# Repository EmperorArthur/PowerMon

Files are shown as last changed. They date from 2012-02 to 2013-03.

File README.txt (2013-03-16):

This is the code and Eagle files for a wireless power monitoring system.
All code and schematics are Copyright Arthur Moore 2013 GPLV3
	If this license is too restrictive for your use, feel free to contact me.

The wireless power monitor works using two boards with IEE 802.15.4 Radios.
One board monitors and transmits power usage data, while the other recieves the data, and sends it on to a computer.

Currently there is one board that does everything.  It uses an ATMega328 microcontroller with an AT86RF231 radio module.

This repository was taken from an SVN snapshot, then sanitized for public release.

The code is in ./Code/Datalogger1/

Important files are:
ADC.h/c:				These are the Analog to Digital Converter functions.
LED.h/c:				Simple functions to controll a LED
Communication.h/c:		Bridge functions, allowing cout to work with both serial and the radio.
UART.h/c:				Serial I/O for cout and cin
Measurements.h/c:		Where the actual measurements are done and calculated.
Datalogger1.c:			The main file.  This is where the important stuff takes place.

Contrary to any common sense, the main board is in ./Eagle Files/Main Board with Headers/

The only header on the board is a SPI programming header.
I normally use an arduino bootloader with the FTDI chip, so it's mostly unused.
There is one wire missing for this configuration.  A wire from the FTDI chip to the reset pin with a small capacitor in series.

I was orriginally using an older version of the radio library provided here:  http://simonetti.media.mit.edu/dev/projects/avrradio
Given my issues with the library documentation and microcontroller space issues, I had to hack the provided library to pieces.
I eventually ended up creating my own library from scratch for this thing.  See my github page for it.

To Do:
	Replace hacked together radio library with the one I created.
	Re-organize the repository so It's easy to understand, and doesn't have as many misc files.
	Completely redesign board for smaller footprint, less component count, and higher acuracy.
	Potentially seperate board into two seperate boards.

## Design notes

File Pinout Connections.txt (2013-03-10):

LED_Out 	PD5
IRQ			PB1
SLP_TR		PB0
/Radio_RST	PD6
CS-SD_Card	PD3

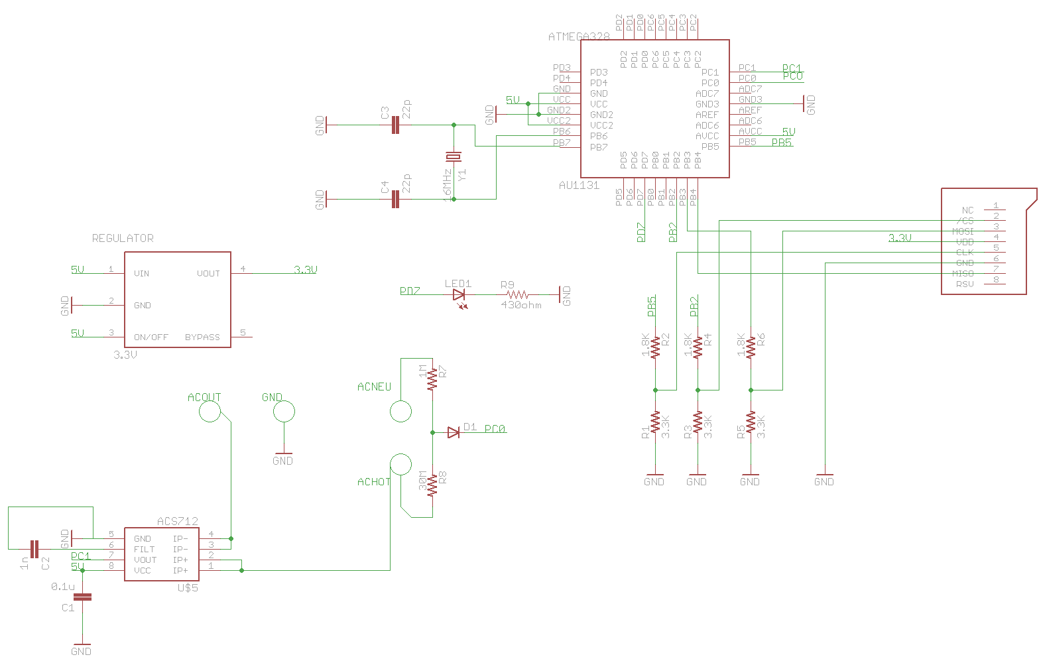
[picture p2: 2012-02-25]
Eagle Files/495Group10/final.png

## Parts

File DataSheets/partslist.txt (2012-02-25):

Crystal 16mHZ---Crystal, HC49US

SENSOR CURRENT 20A 5V BI 8-SOIC---- ACS712, SOIC-8

CONN MINI MICRO-SD 8PIN PCB GOLD---Micro SD socket PP

RES 909K OHM 1/4W 1% 1206 SMD---AXIAL-0.4, R1206, R1206W

RES 30M OHM 1/8W 5% 0805 SMD---R0805W, or R0805

ATMEGA328-AU---ATMEGA328,TQFP32A

IC LDO REG 3.3V 150MA SOT23-5---REG3.3V, SOT23-5

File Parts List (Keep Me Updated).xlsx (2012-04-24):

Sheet: Sheet1
Qty | Value | Device | Parts | Price Per Part | Price Per Board | For 3 Boards | Part Order Page | Part Description | Minimum Order
1 | ACS712 | ACS712 | CURRENT_SENSOR | $4.52 | $4.52 | $13.56 | http://parts.digikey.com/1/parts/945626-sensor-current-20a-5v-bi-8-soic-acs712elctr-20a-t.html | current-sensor | 3
1 | ANTENNA2SMD | ANTENNA2SMD | ANTENNA | $0.84 | $0.84 | $8.44 | http://search.digikey.com/us/en/products/2450AT18B100E/712-1006-1-ND/1560835 | RF antenna | Order at least 10
1 | AT86RF231(RADIO)AT86RF231 | AT86RF231(RADIO)AT86RF231 | AT86RF231 | $4.73 | $4.73 | $14.19 | http://search.digikey.com/us/en/products/AT86RF231-ZU/AT86RF231-ZU-ND/1870495 | radio | 3
1 | ATMEGA32832A | ATMEGA32832A | ATMEGA328 | $3.83 | $3.83 | $11.49 | http://parts.digikey.com/1/parts/1877362-ic-mcu-avr-32k-flash-32tqfp-atmega328-au.html | atmega | 3
1 | AVR_SPI_PRG_6PTH | AVR_SPI_PRG_6PTH | ISP_HEADER | $0.39 | $0.39 | $3.15 | http://search.digikey.com/us/en/products/961206-6404-AR/3M9459-ND/2071500 | ISP header | Order at least 10
2 | 0.1u | CAP0603-CAP | C1, C9 | $0.01 | $0.02 | $0.76 | http://search.digikey.com/us/en/products/CC0603ZRY5V9BB104/311-1343-1-ND/2103127 | 0.1uF Cap | Order at least 100
4 | 1 uF | CAP0603-CAP | CB1, CB2, CB3, CB4 | $0.02 | $0.07 | $1.87 | http://search.digikey.com/us/en/products/C1608Y5V1A105Z/445-1328-1-ND/567635 | 1 uF Caps | Order at least 100
1 | 1n | CAP0603-CAP | C2 | $0.02 | $0.02 | $1.53 | http://search.digikey.com/us/en/products/GRM188R71H102KA01D/490-1494-1-ND/587851 | 1nF Cap | Order at least 100
1 | 10 nF | CAP0603-CAP | C12 | $0.01 | $0.01 | $1.40 | http://search.digikey.com/us/en/products/GRM188R71H103KA01D/490-1512-1-ND/587862 | 10nF Cap | Order at least 100
2 | 12 pF | CAP0603-CAP | CX1, CX2 | $0.01 | $0.03 | $1.38 | http://search.digikey.com/us/en/products/C1608C0G1H120J/445-1270-1-ND/567672 | 12pF Caps | Order at least 100
4 | 22 pF | CAP0603-CAP | C3, C4, C10, C11 | $0.01 | $0.06 | $1.38 | http://search.digikey.com/us/en/products/C1608C0G1H220J/445-1273-1-ND/567670 | 22pF Caps | Order at least 100
3 |  | CAPPTH1 | C6, C7, C8 | - | - | - | - | Ignore these
1 | 3300µF | CAPPTH1 | C5 | $0.90 | $0.90 | $2.70 | http://search.digikey.com/us/en/products/ECA-1CM332/P5144-ND/245003 | 3300uF Cap | 3
2 | 16 MHZ | CRYSTALSMD | Y1, Y2 | $0.36 | $0.72 | $3.58 | http://parts.digikey.com/1/parts/1800664-crystal-16-000-mhz-18pf-smd-abls-16-000mhz-b4-t.html | 16mhz crystal | Order at least 10
1 | 115V -> 5V | EI38-2 | MT2201 | $4.96 | $4.96 | $14.88 | http://search.digikey.com/us/en/products/3FS-210/MT2201-ND/285599 | transformer | 3
1 | FT232RL | FT232RL | IC1 | $4.50 | $4.50 | $13.50 | http://search.digikey.com/scripts/DkSearch/dksus.dll?Detail&itemSeq=112820000&uq=634689795876532809 | USB-Serial Chip | 3
2 | Green | LED0603 | PWR, RF-RX | $0.09 | $0.19 | $2.34 | http://search.digikey.com/us/en/products/APT1608SGC/754-1121-1-ND/1747838 | green led | Order at least 25
2 | Red | LED0603 | RF-TX, STATUS | $0.09 | $0.19 | $2.34 | http://search.digikey.com/us/en/products/APT1608EC/754-1117-1-ND/1747834 | red led | Order at least 25
2 | MB4S | MB4S | B1, B2 | $0.41 | $0.83 | $4.14 | http://search.digikey.com/scripts/DkSearch/dksus.dll?Detail&itemSeq=112820148&uq=634689795876532809 | bridge rectifier | Order at least 10
1 | MICROSD | MICROSD | MICROSD | $1.94 | $1.94 | $5.82 | http://parts.digikey.com/1/parts/1804297-conn-mini-micro-sd-8pin-pcb-gold-101-00581-59.html | microsd | 3
1 | MINI-USB-UX60A-MB-5ST | MINI-USB-UX60A-MB-5ST | X2 | $1.02 | $1.02 | $10.23 | http://search.digikey.com/us/en/products/UX60A-MB-5ST/H2961CT-ND/597540 | mini USB | Order at least 10
3 |  | PTH3MM | ACHOT, ACNEU, ACOUT | - | - | - | - | Ignore these
1 | REG3.3V | REG3.3V | 3.3V_REGULATOR | $0.54 | $0.54 | $5.42 | http://parts.digikey.com/1/parts/609150-ic-ldo-reg-3-3v-150ma-sot23-5-lp2985-33dbvr.html | 3.3v regulator | Order at least 10
5 | 10K | RESISTOR0603-RES | R1, R2, R3, R4, R13 | $0.02 | $0.08 | $1.58 | http://search.digikey.com/us/en/products/RNCP0603FTD10K0/RNCP0603FTD10K0CT-ND/2240478 | 10k resistor | Order at least 100
1 | 37.4K | RESISTOR0603-RES | R12 | $0.02 | $0.02 | $1.58 | http://search.digikey.com/us/en/products/RNCP0603FTD37K4/RNCP0603FTD37K4CT-ND/2240497 | 37.4K resistor | Order at least 100
3 | 100 | RESISTOR0603-RES | R5, R6, R9 | $0.02 | $0.05 | $1.58 | http://search.digikey.com/us/en/products/RNCP0603FTD100R/RNCP0603FTD100RCT-ND/2240425 | 100 ohm resistor | Order at least 100
4 | STAND-OFF | STAND-OFF | JP1, JP2, JP3, JP4 | - | - | - | - | Ignore these
1 | WE-BAL | WE-BAL | BALUN | $2.58 | $2.58 | $7.74 | http://parts.digikey.com/1/parts/1790682-balun-ember351-357-0805-smd-748421245.html | balun | 3
1 |  |  | To Outlet | $0.80 | $0.80 | $7.97 | http://search.digikey.com/us/en/products/703W-00%2F07/Q335-ND/1164206 | Euro IN | Order at least 10
1 |  |  | To Device | $1.13 | $1.13 | $3.39 | http://search.digikey.com/us/en/products/4300.0701/486-1082-ND/1207600 | Edison Out | 3
1 |  |  | Fuse Holder | $1.83 | $1.83 | $9.16 | http://search.digikey.com/us/en/products/03540901ZXGY/F3131-ND/554005 | fuse holder | Order at least 5
1 |  |  | Fuse | $0.33 | $0.33 | $3.28 | http://search.digikey.com/us/en/products/3SB%2015-R/507-1537-ND/1009761 | 15A Fuse | Order at least 10
1 |  |  | Case | $5.83 | $5.83 | $17.49 | http://search.digikey.com/us/en/products/133,BK/SR133B-ND/95399 | Enclosure | 3
 |  |  | Wire
 |  |  | Board Cost | See Provided Rubric |  |  | http://www.pcb-pool.com/ppus/order_productconfiguration_js.html
1 |  |  | Alternate Resistor | $0.02 | $0.02 | $1.58 | http://search.digikey.com/us/en/products/RNCP0603FTD7K50/RNCP0603FTD7K50CT-ND/2240474 | 7.5K Alternate | Order at least 100
1 |  |  | Alternate Resistor | $0.02 | $0.02 | $1.58 | http://search.digikey.com/us/en/products/RNCP0603FTD14K0/RNCP0603FTD14K0CT-ND/2240484 | 14K Alternate | Order at least 100
 |  |  |  |  | $42.97 | $181.03 | Total
 |  |  |  |  |  | -$52.12 | Cost overhead from spare/unused parts

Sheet: Sheet2
Qty | Value | Device | Parts
1 | ACS712 | ACS712 | CURRENT_SENSOR
1 | ANTENNA2SMD | ANTENNA2SMD | ANTENNA
1 | AT86RF231(RADIO)AT86RF231 | AT86RF231(RADIO)AT86RF231 | AT86RF231
1 | ATMEGA32832A | ATMEGA32832A | ATMEGA328
1 | AVR_SPI_PRG_6PTH | AVR_SPI_PRG_6PTH | ISP_HEADER
2 | 0.1u | CAP0603-CAP | C1, C9
4 | 1 uF | CAP0603-CAP | CB1, CB2, CB3, CB4
1 | 1n | CAP0603-CAP | C2
1 | 10 nF | CAP0603-CAP | C12
2 | 12 pF | CAP0603-CAP | CX1, CX2
4 | 22 pF | CAP0603-CAP | C3, C4, C10, C11
3 |  | CAPPTH1 | C6, C7, C8
1 | 3300µF | CAPPTH1 | C5
2 | 16 MHZ | CRYSTALSMD | Y1, Y2
1 | 115V -> 5V | EI38-2 | MT2201
1 | FT232RL | FT232RL | IC1
2 | Green | LED0603 | PWR, RF-RX
2 | Red | LED0603 | RF-TX, STATUS
2 | MB4S | MB4S | B1, B2
1 | MICROSD | MICROSD | MICROSD
1 | MINI-USB-UX60A-MB-5ST | MINI-USB-UX60A-MB-5ST | X2
3 |  | PTH3MM | ACHOT, ACNEU, ACOUT
1 | REG3.3V | REG3.3V | 3.3V_REGULATOR
5 | 10K | RESISTOR0603-RES | R1, R2, R3, R4, R13
1 | 37.4K | RESISTOR0603-RES | R12
3 | 100 | RESISTOR0603-RES | R5, R6, R9
4 | STAND-OFF | STAND-OFF | JP1, JP2, JP3, JP4
1 | WE-BAL | WE-BAL | BALUN

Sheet: Sheet3
$0.05 | $0.24 | $1.90 | http://search.digikey.com/us/en/products/4-103741-0/A26509-40-ND/297917 | Pins for Jumper | no | This is for 40, our jumper uses 3

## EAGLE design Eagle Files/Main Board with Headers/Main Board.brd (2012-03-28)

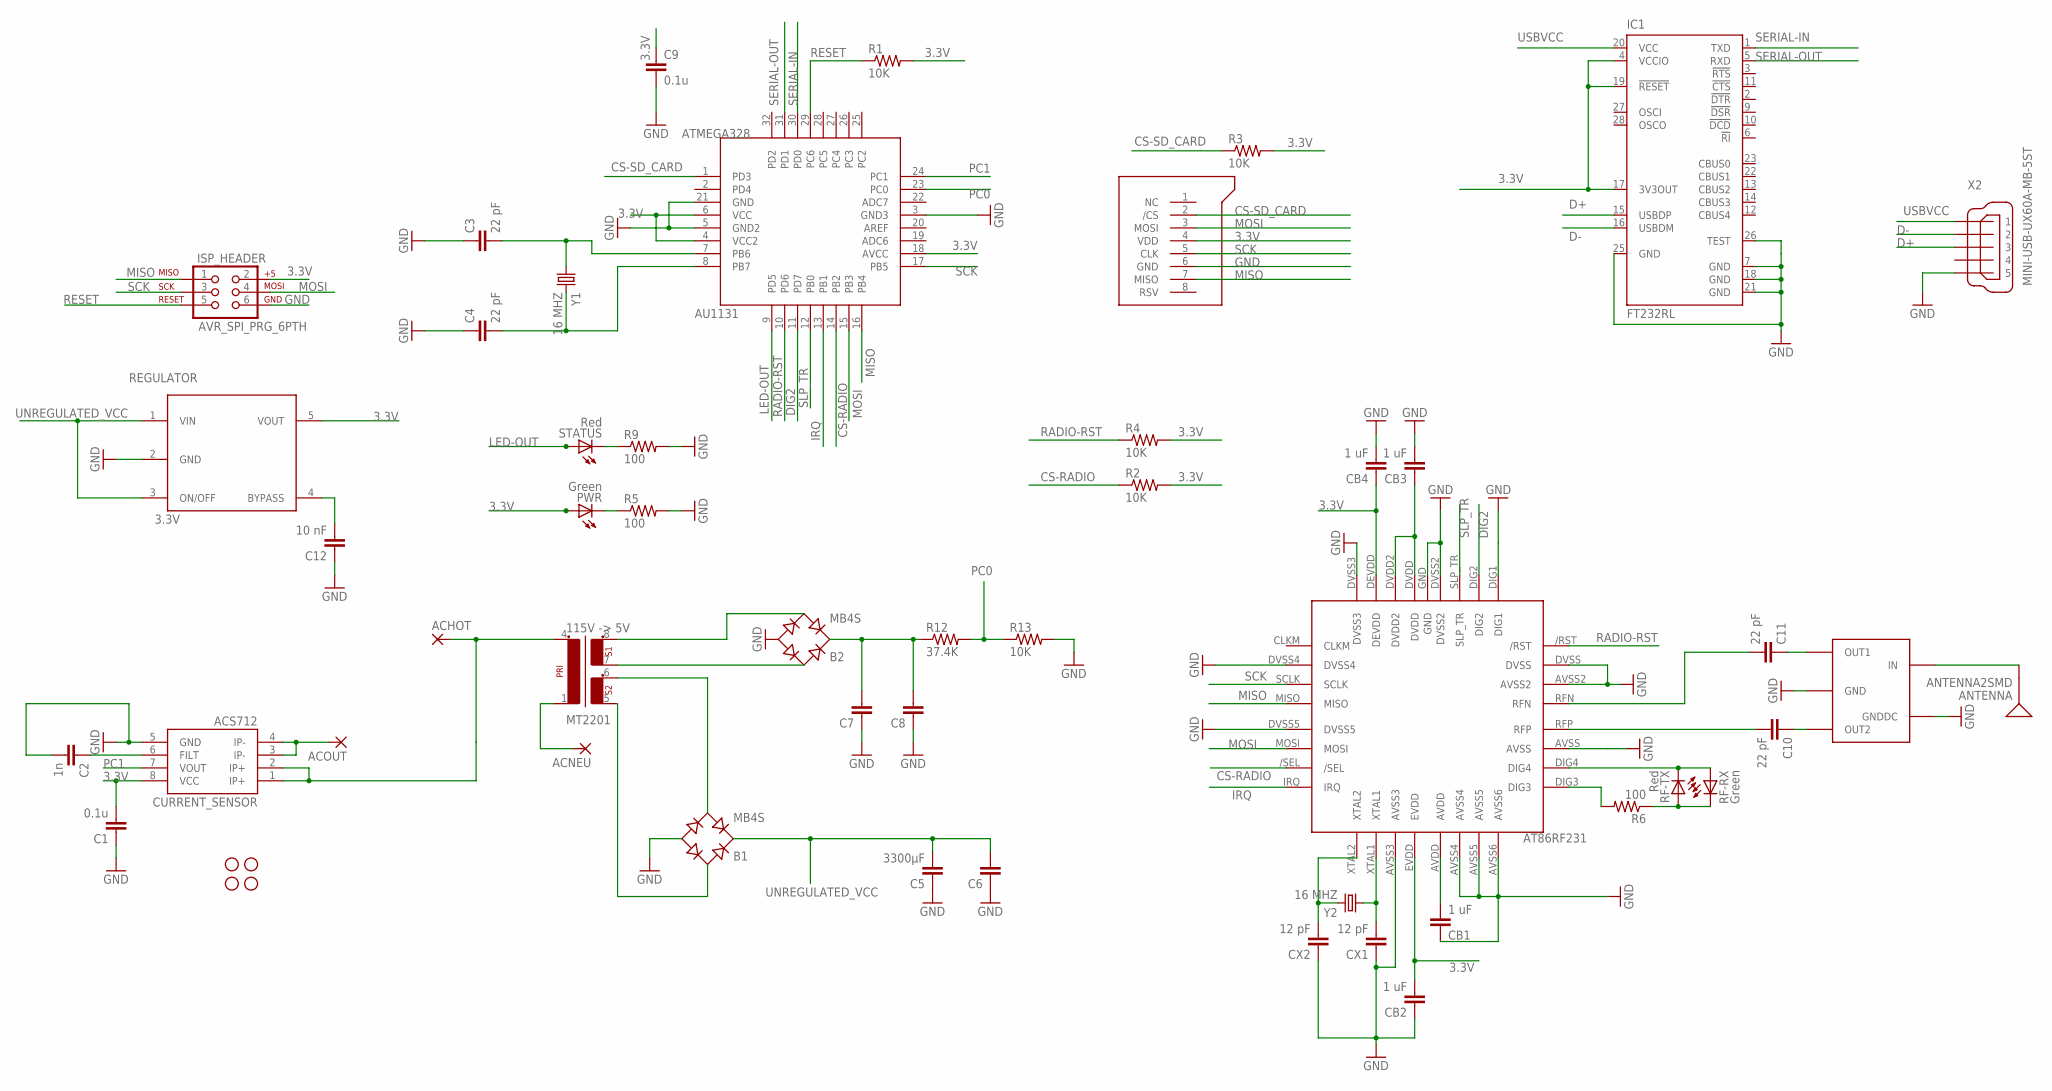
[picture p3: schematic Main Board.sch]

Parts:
3.3V_REGULATOR: REG3.3V; SOT23-5
ACHOT: PTH3MM; PTH-3MM
ACNEU: PTH3MM; PTH-3MM
ACOUT: PTH3MM; PTH-3MM
ANTENNA: ANTENNA2SMD; ANTENNA-CHIP2
AT86RF231: AT86RF231(RADIO)AT86RF231; 32QN2(RADIO)
ATMEGA328: ATMEGA32832A; TQFP32-08
B1, B2: MB4S; SOIC-4
BALUN: WE-BAL
C1, C9: 0.1u; 0603-CAP
C2: 1n; 0603-CAP
C3, C4, C10, C11: 22 pF; 0603-CAP
C5: 3300µF; CAP-PTH-5MM
C6, C7, C8: CAPPTH1; CAP-PTH-5MM
C12: 10 nF; 0603-CAP
CB1, CB2, CB3, CB4: 1 uF; 0603-CAP
CURRENT_SENSOR: ACS712; SO08
CX1, CX2: 12 pF; 0603-CAP
IC1: FT232RL; SSOP28
ISP_HEADER: AVR_SPI_PRG_6PTH; 2X3
JP1, JP2, JP3, JP4: STAND-OFF
MICROSD: MICROSD; MICRO-SD-SOCKET-PP
MT2201: 115V -> 5V; EI38-2
PWR: Green; LED-0603
R1, R2, R3, R4, R13: 10K; 0603-RES
R5, R6, R9: 100; 0603-RES
R12: 37.4K; 0603-RES
RF-RX: Green; LED-0603
RF-TX: Red; LED-0603
STATUS: Red; LED-0603
X2: MINI-USB-UX60A-MB-5ST; UX60A-MB-5ST
Y1, Y2: 16 MHZ; HC49UP

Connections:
3.3V: 3.3V_REGULATOR.5 (VOUT), AT86RF231.DEVDD, AT86RF231.EVDD, ATMEGA328.4 (VCC2), ATMEGA328.6 (VCC), ATMEGA328.18 (AVCC), C1.2, C9.1, CB2.2, CB4.1, CURRENT_SENSOR.8 (VCC), IC1.4 (VCCIO), IC1.17 (3V3OUT), IC1.19 (!RESET), ISP_HEADER.2, MICROSD.4 (VDD), PWR.A, R1.2, R2.2, R3.2, R4.2
3.3V1: 3.3V_REGULATOR.4 (BYPASS), C12.2
CS-RADIO: AT86RF231./SEL, ATMEGA328.14 (PB2), R2.1
CS-SD_CARD: ATMEGA328.1 (PD3), MICROSD.2 (/CS), R3.1
D+: IC1.15 (USBDP), X2.3
D-: IC1.16 (USBDM), X2.2
DIG2: AT86RF231.DIG2, ATMEGA328.11 (PD7)
GND: 3.3V_REGULATOR.2 (GND), AT86RF231.AVSS, AT86RF231.AVSS2, AT86RF231.AVSS3, AT86RF231.AVSS4, AT86RF231.AVSS5, AT86RF231.AVSS6, AT86RF231.DIG1, AT86RF231.DVSS, AT86RF231.DVSS2, AT86RF231.DVSS3, AT86RF231.DVSS4, AT86RF231.DVSS5, AT86RF231.GND, ATMEGA328.3 (GND3), ATMEGA328.5 (GND2), ATMEGA328.21 (GND), B1.-, B2.-, BALUN.GND, BALUN.GNDDC, C1.1, C2.2, C3.1, C4.1, C5.1, C6.1, C7.1, C8.1, C9.2, C12.1, CB1.1, CB2.1, CB3.2, CB4.2, CURRENT_SENSOR.5 (GND), CX1.1, CX2.1, IC1.7 (GND), IC1.18 (GND), IC1.21 (GND), IC1.25 (GND), IC1.26 (TEST), ISP_HEADER.6, MICROSD.6 (GND), R5.2, R9.2, R13.2, X2.5
IRQ: AT86RF231.IRQ, ATMEGA328.13 (PB1)
LED-OUT: ATMEGA328.9 (PD5), STATUS.A
MISO: AT86RF231.MISO, ATMEGA328.16 (PB4), ISP_HEADER.1, MICROSD.7 (MISO)
MOSI: AT86RF231.MOSI, ATMEGA328.15 (PB3), ISP_HEADER.4, MICROSD.3 (MOSI)
unnamed: ACHOT.1, CURRENT_SENSOR.1 (IP+), CURRENT_SENSOR.2 (IP+), MT2201.4
unnamed: ACNEU.1, MT2201.1
unnamed: B1.~1 (AC1), MT2201.5
unnamed: B2.~1 (AC1), MT2201.7
unnamed: B2.~2 (AC2), MT2201.8
unnamed: B2.+, C7.2, C8.2, R12.1
unnamed: PWR.C, R5.1
unnamed: AT86RF231.DVDD, AT86RF231.DVDD2, CB3.1
unnamed: ACOUT.1, CURRENT_SENSOR.3 (IP-), CURRENT_SENSOR.4 (IP-)
unnamed: AT86RF231.AVDD, CB1.2
unnamed: AT86RF231.XTAL1, CX1.2, Y2.1
unnamed: AT86RF231.XTAL2, CX2.2, Y2.2
unnamed: AT86RF231.DIG4, RF-RX.A, RF-TX.C
unnamed: R6.1, RF-RX.C, RF-TX.A
unnamed: AT86RF231.DIG3, R6.2
unnamed: BALUN.OUT2, C10.1
unnamed: BALUN.OUT1, C11.1
unnamed: AT86RF231.RFN, C11.2
unnamed: AT86RF231.RFP, C10.2
unnamed: ANTENNA.FEED, BALUN.IN
unnamed: B1.~2 (AC2), MT2201.6
unnamed: C2.1, CURRENT_SENSOR.6 (FILT)
unnamed: R9.1, STATUS.C
PC0: ATMEGA328.23 (PC0), R12.2, R13.1
PC1: ATMEGA328.24 (PC1), CURRENT_SENSOR.7 (VOUT)
RADIO-RST: AT86RF231./RST, ATMEGA328.10 (PD6), R4.1
RESET: ATMEGA328.29 (PC6), ISP_HEADER.5, R1.1
SCK: AT86RF231.SCLK, ATMEGA328.17 (PB5), ISP_HEADER.3, MICROSD.5 (CLK)
SERIAL-IN: ATMEGA328.30 (PD0), IC1.1 (TXD)
SERIAL-OUT: ATMEGA328.31 (PD1), IC1.5 (RXD)
SLP_TR: AT86RF231.SLP_TR, ATMEGA328.12 (PB0)
UNREGULATED_VCC: 3.3V_REGULATOR.1 (VIN), 3.3V_REGULATOR.3 (ON/OFF), B1.+, C5.2, C6.2
USBVCC: IC1.20 (VCC), X2.1
XTAL1: ATMEGA328.7 (PB6), C3.2, Y1.1
XTAL2: ATMEGA328.8 (PB7), C4.2, Y1.2

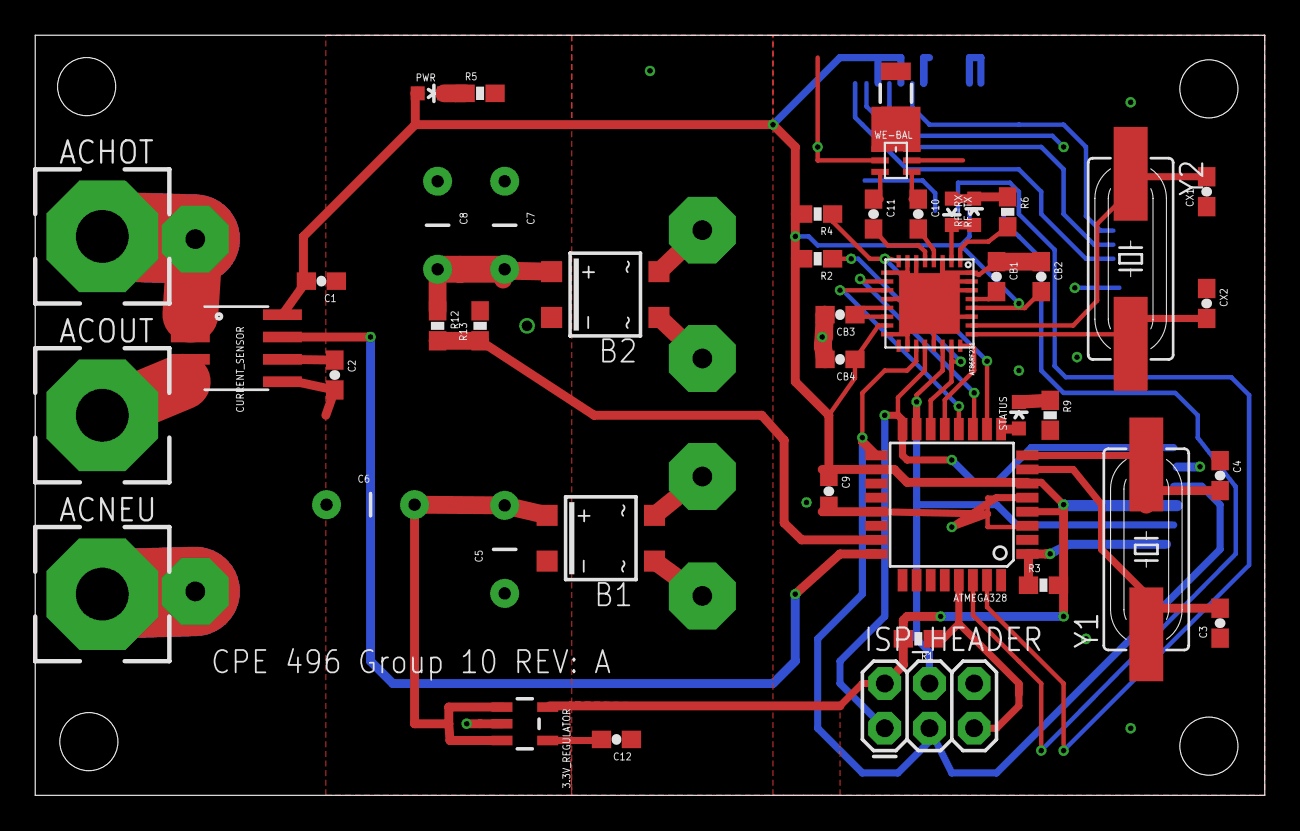
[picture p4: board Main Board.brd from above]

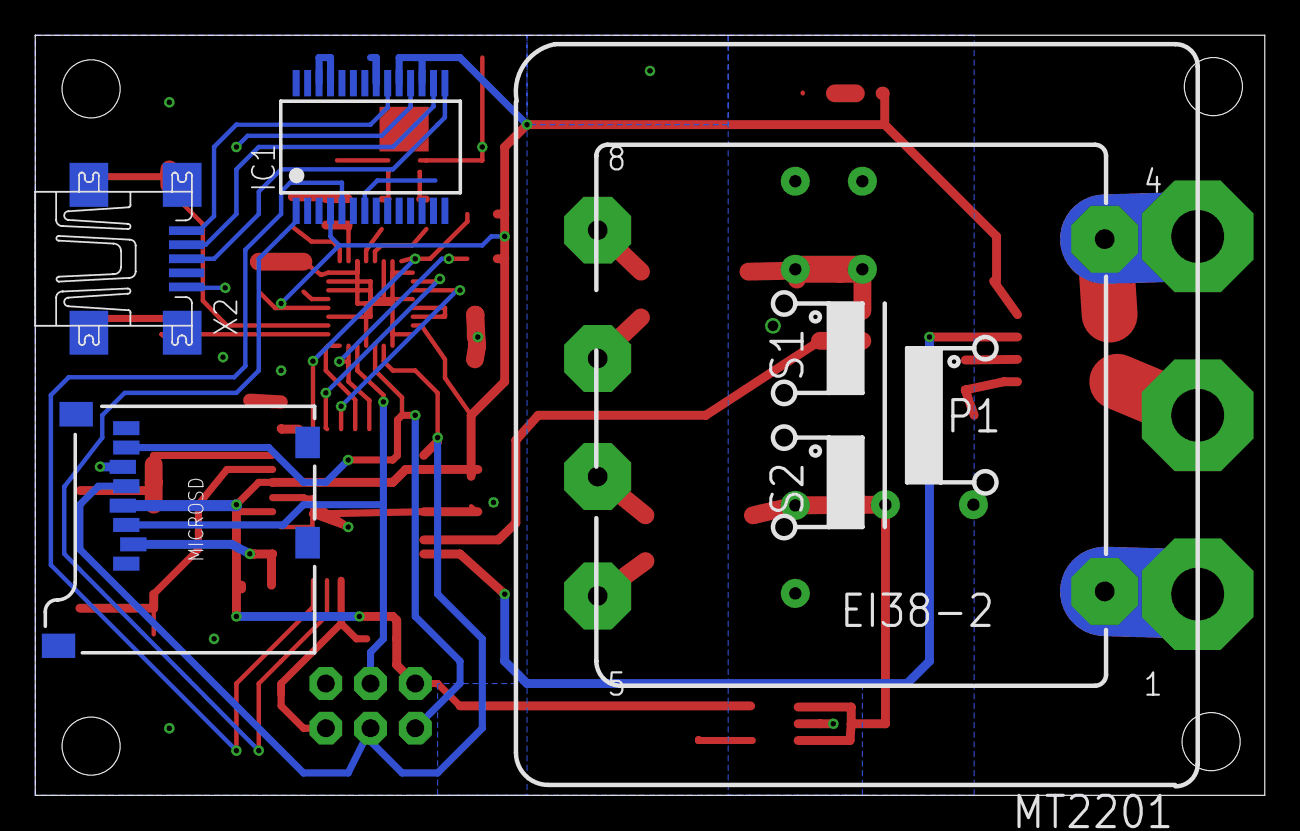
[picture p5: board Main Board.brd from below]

Board: 2 copper layers, 69.8 x 43.2 mm, 53 parts (4 on the bottom side), 47 nets.

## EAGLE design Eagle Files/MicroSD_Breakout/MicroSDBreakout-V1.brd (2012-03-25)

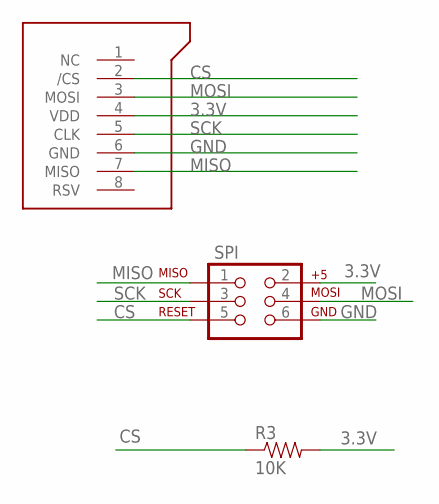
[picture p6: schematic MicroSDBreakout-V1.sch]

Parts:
R3: 10K; 0603-RES
SPI: AVR_SPI_PRG_6PTH; 2X3
U$1: MICROSD; MICRO-SD-SOCKET-PP

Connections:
3.3V: R3.2, SPI.2, U$1.4 (VDD)
CS: R3.1, SPI.5, U$1.2 (/CS)
GND: SPI.6, U$1.6 (GND)
MISO: SPI.1, U$1.7 (MISO)
MOSI: SPI.4, U$1.3 (MOSI)
SCK: SPI.3, U$1.5 (CLK)

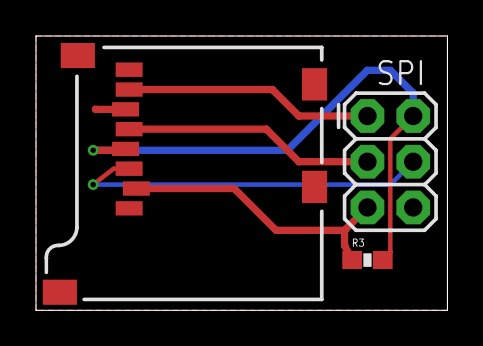
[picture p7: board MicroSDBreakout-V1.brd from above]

Board: 2 copper layers, 22.9 x 15.2 mm, 3 parts (0 on the bottom side), 6 nets.

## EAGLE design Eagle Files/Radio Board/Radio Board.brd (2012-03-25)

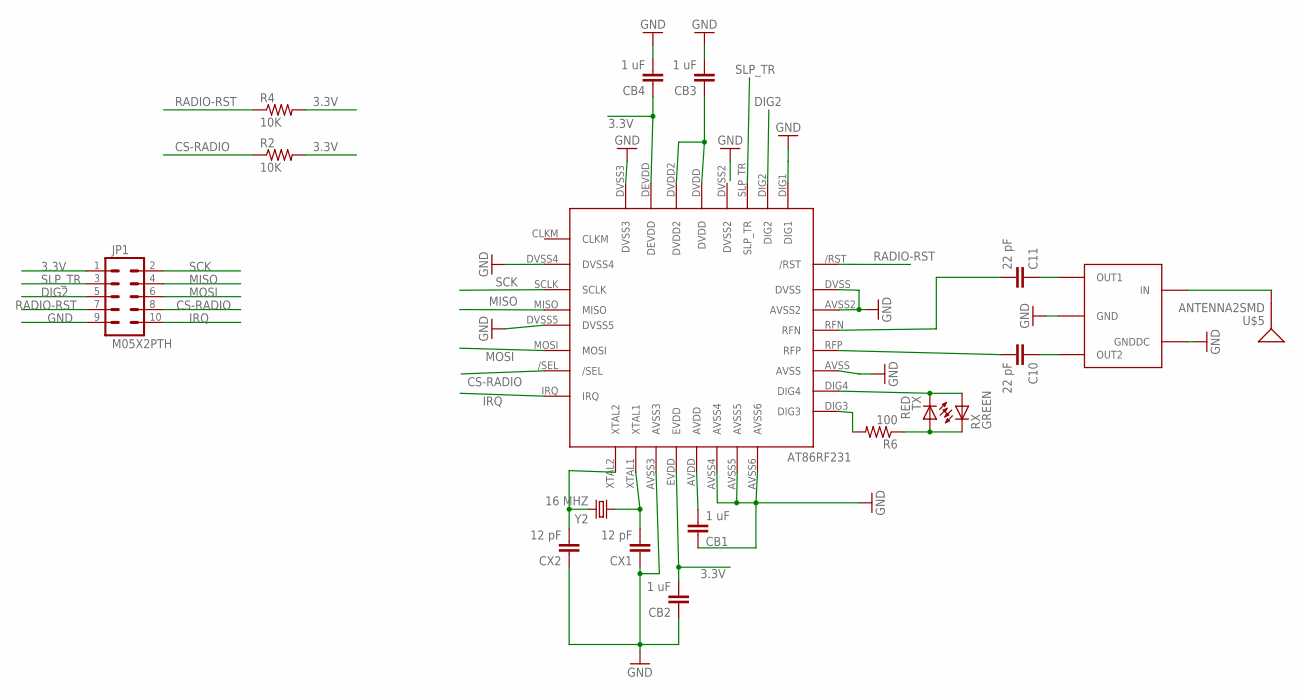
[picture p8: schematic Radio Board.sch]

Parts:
C10, C11: 22 pF; 0603-CAP
CB1, CB2, CB3, CB4: 1 uF; 0603-CAP
CX1, CX2: 12 pF; 0603-CAP
JP1: M05X2PTH; AVR_ICSP
R2, R4: 10K; 0603-RES
R6: 100; 0603-RES
RX: GREEN; LED-0603
TX: RED; LED-0603
U$3: AT86RF231(RADIO)AT86RF231; 32QN2(RADIO)
U$4: WE-BAL
U$5: ANTENNA2SMD; ANTENNA-CHIP2
Y2: 16 MHZ; HC49UP

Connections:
3.3V: CB2.2, CB4.1, JP1.1, R2.2, R4.2, U$3.DEVDD, U$3.EVDD
CS-RADIO: JP1.8, R2.1, U$3./SEL
DIG2: JP1.5, U$3.DIG2
GND: CB1.1, CB2.1, CB3.2, CB4.2, CX1.1, CX2.1, JP1.9, U$3.AVSS, U$3.AVSS2, U$3.AVSS3, U$3.AVSS4, U$3.AVSS5, U$3.AVSS6, U$3.DIG1, U$3.DVSS, U$3.DVSS3, U$3.DVSS4, U$3.DVSS5, U$4.GND, U$4.GNDDC
IRQ: JP1.10, U$3.IRQ
MISO: JP1.4, U$3.MISO
MOSI: JP1.6, U$3.MOSI
unnamed: CB3.1, U$3.DVDD, U$3.DVDD2
unnamed: CB1.2, U$3.AVDD
unnamed: CX1.2, U$3.XTAL1, Y2.1
unnamed: CX2.2, U$3.XTAL2, Y2.2
unnamed: RX.A, TX.C, U$3.DIG4
unnamed: R6.1, RX.C, TX.A
unnamed: R6.2, U$3.DIG3
unnamed: C10.1, U$4.OUT2
unnamed: C11.1, U$4.OUT1
unnamed: C11.2, U$3.RFN
unnamed: C10.2, U$3.RFP
unnamed: U$4.IN, U$5.FEED
RADIO-RST: JP1.7, R4.1, U$3./RST
SCK: JP1.2, U$3.SCLK
SLP_TR: JP1.3, U$3.SLP_TR

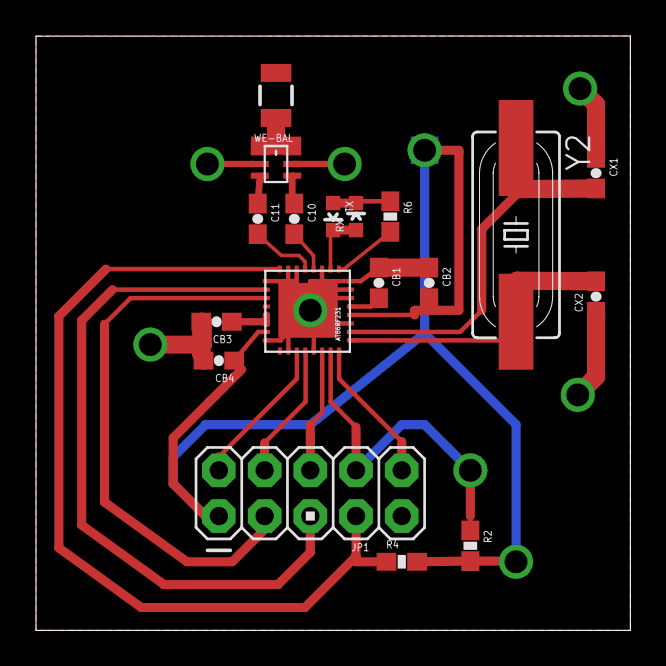
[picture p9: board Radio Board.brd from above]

Board: 2 copper layers, 33.0 x 33.0 mm, 18 parts (0 on the bottom side), 22 nets.

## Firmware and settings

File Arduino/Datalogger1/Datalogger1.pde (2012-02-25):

/*
  SD card datalogger
 
  HEAVILY MODIFIED BY GROUP 10
  WARNING: analogRead and string functions and classes DO NOT WORK.
 
 This example shows how to log data from three analog sensors 
 to an SD card using the SD library.
 
 	
 The circuit:
 * analog sensors on analog ins 0, 1, and 2
 * SD card attached to SPI bus as follows:
 ** MOSI - pin 11
 ** MISO - pin 12
 ** CLK - pin 13
 ** CS - pin 10
 
 created  24 Nov 2010
 updated 2 Dec 2010
 by Tom Igoe
 
 	 
 */
 
//We need a nop function
#define _NOP() __asm__ __volatile__("nop")
//Uncomment this to enable serial output (WARNING, serial output currently does not work with SD card, not enough RAM)
#define TESTSERIALOUT 1;
// The pin my status indicator LED is on
#define LEDPIN 7

#include <SD.h>


const int chipSelect = 10;
int flipflop=LOW;  //This is used to let me switch my LED on and off easily.

//Set up my A/D Converter
void ADC_setup(){
  DDRC = 0;      //All of Port C is an input
  PORTC = 0;     //With All of my pull up resistors Disabled
  ADMUX  = _BV(REFS0);     //Reset whatever Arduino has done, and choose ADC0 to get our data from
  ADCSRA = _BV(ADEN)| _BV(ADPS2) | _BV(ADPS1) | _BV(ADPS0);  //Enable the ADC, while at the same time removing whatever the Arduino stuff has done to everything.
}

//Read from the specified ADC pin
uint16_t ADC_read(unsigned char pin){
  unsigned char temp, low, high;
  //Select which pin I'm going to be reading
  temp = (ADMUX & 0xf0) | (pin & 0x0f);
  ADMUX = temp;
  ADCSRA |= _BV(ADSC); //Start the conversion
  
  //Keep checking and waiting until the conversion is complete
  while(!(ADCSRA&_BV(ADIF))){
    _NOP();
  }
  low = ADCL;
  high = ADCH;
  return (high << 8)  | low;
}

void SD_setup(){
  #ifdef TESTSERIALOUT
    Serial.println("Initializing SD card...");
  #endif
  // make sure that the default chip select pin is set to
  // output, even if you don't use it:
  
  // see if the card is present and can be initialized:
  if (!SD.begin(chipSelect)) {
    #ifdef TESTSERIALOUT
      Serial.println("Card failed, or not present");
    #endif
    // don't do anything more:
    //return;
  }
  #ifdef TESTSERIALOUT
    Serial.println("card initialized.");
  #endif
}

void SizeSafetyCheck(File fileToCheck){
  //If File is near/over 3GB stop, and blink the LED slowly
  if(fileToCheck.size() > 24000000000.0){
    while(1){
      if(flipflop==HIGH){
        flipflop = LOW;
      }else{
        flipflop = HIGH;
      }
      digitalWrite(LEDPIN, flipflop);   // set the LED
    delay(10000);
    }
  }
}

void BlinkLED(unsigned long milliseconds){
  digitalWrite(LEDPIN,HIGH);
  delay(milliseconds);
  digitalWrite(LEDPIN,LOW);
}

struct VoltageStruct{
  double Voltage;        //This will be my final value
  uint32_t megaVoltage;  //I'm constantly adding lastADCValue squared to this so I can use it to find RMS values
  uint16_t numSamples;   //Number of samples measured
  unsigned long time;    //The time it took me to do all of this
  //Measure the voltage assuming that it's a half rectified signal.
  //Measure the voltage on the selected pin
  void DoIt(unsigned char  pin){
    //Initalize variables
    Voltage = 0;
    megaVoltage = 0;
    numSamples = 0;
    
    uint16_t lastADCValue = 1023; //This needs to be max for my first while loop. 
    uint16_t threashhold = 35;  //Below this value we assume we are only seeing noise.

    //If we start in the middle of a wave, wait untill the next wave before continuing
    while(lastADCValue > threashhold){
      lastADCValue = ADC_read(0);
    }
    while(lastADCValue < threashhold){
      lastADCValue = ADC_read(0);
    }

    //Work and Sample at the same time 
    unsigned long startTime = micros();
    while(lastADCValue > threashhold){
      //Select which pin I'm going to be reading
      unsigned char temp = (ADMUX & 0xf0) | (pin & 0x0f);
      ADMUX = temp;
      //Start the conversion
      ADCSRA |= _BV(ADSC);
      
      //Do Work While waiting for conversion to finish
      megaVoltage += lastADCValue * lastADCValue;
      
      //Keep checking and waiting until the conversion is complete
      while(!(ADCSRA&_BV(ADIF))){
        _NOP();
      }
      //Convert the Conversion into one number
      unsigned char low = ADCL;
      unsigned char high = ADCH;
      lastADCValue = (high << 8)  | low;
      
      //Increment my number of samples
      numSamples++;
    }
    unsigned long endTime = micros();


    //Sanity check, in case noise set it off
    if(numSamples < 60){
      Voltage = 0;
      return;
    }
    
    //Find RMS using megaVoltage
    Voltage = megaVoltage/numSamples;
    Voltage = sqrt(Voltage);
    
    //Convert to real values
    //Should be Voltage = (ADCValue * (5V reference/1024 divisions) + 0.7V to compensate for our diode) * 31 for our voltage divider
    //But our diode is acting up, and is instead causing a massive voltage drop (2.8 V instead of 0.7V)
    Voltage = (Voltage * 5/1024.0 + 2.8) * 31;
    
    //Calculate total time
    time = endTime-startTime;
  }
};

struct AmperageStruct{
  double Amperage;        //This will be my final value
  uint32_t megaAmperage;  //Highest Value Seen from my Hall Effect Sensor
  uint16_t numSamples;   //Number of samples measured
  unsigned long time;    //The time it took me to do all of this
  //Measure the Amperage on the selected pin (using the output from an ACS712 20A Current sensor)
  void DoIt(unsigned char  pin){
    //Initalize variables
    Amperage = 0;
    megaAmperage = 0;
    numSamples = 0;
    
    uint16_t lastADCValue = 0; //The Last value of the ADC

    unsigned long startTime = millis();
	//Sample for 30 milliseconds & output highest vlue seen
    while((millis()-startTime)<30){
      lastADCValue = ADC_read(1);
      if(lastADCValue > megaAmperage)
        megaAmperage = lastADCValue;
      numSamples++;
    }
    unsigned long endTime = millis();
    time = endTime-startTime;
    
    //8 Amps/Volt from my current sensor, with an offset of 2.5V
    Amperage = (megaAmperage * 5/1024.0 - 2.5) * 8;
  }
};

void setup()
{
  pinMode(10, OUTPUT);
  pinMode(LEDPIN, OUTPUT);
  BlinkLED(100);
  #ifdef TESTSERIALOUT
    Serial.begin(9600);
  #endif
  SD_setup();
  BlinkLED(100);
}

void loop()
{
  // open the file. note that only one file can be open at a time,
  // so you have to close this one before opening another.
  File dataFile;
  dataFile = SD.open("datalog.txt", FILE_WRITE);
  
  //File Size check, sanity keeper
  SizeSafetyCheck(dataFile);
  

  // if the file is available, write to it:
  if (dataFile) {

    //   A/D conversion
    ADC_setup();
    
    //Measure Voltage
    VoltageStruct measureVoltage;
    measureVoltage.DoIt(0);
    
    //Measure Amperage
    AmperageStruct measureAmperage;
    measureAmperage.DoIt(1);
    
      //Output our data/results
      dataFile.print(measureVoltage.Voltage);
      dataFile.print(" V RMS; ");
      dataFile.print(measureAmperage.Amperage);
      dataFile.print(" A RMS; ");
      dataFile.print(measureAmperage.Amperage*measureVoltage.Voltage);
      dataFile.print(" W RMS; ");
//      dataFile.print(measureVoltage.numSamples);
//      dataFile.print(" samples for V; ");
//      dataFile.print(measureAmperage.numSamples);
//      dataFile.print(" samples for A; ");
//      dataFile.print(measureVoltage.time);
//      dataFile.print(" microseconds for V");
//      dataFile.print(measureAmperage.time);
//      dataFile.print(" milliseconds for A");
      dataFile.write('\n');
      dataFile.flush();
      dataFile.close();
      
      // print to the serial port too:
      #ifdef TESTSERIALOUT
        Serial.print(measureVoltage.Voltage);
        Serial.print(" V RMS; ");
        Serial.print(measureAmperage.Amperage);
        Serial.print(" A RMS; ");
        Serial.print(measureAmperage.Amperage*measureVoltage.Voltage);
        Serial.print(" W RMS; ");
        Serial.print("\n");
      #endif
    
    
    
    //Blink the LED to let us know that we're done, and can remove the SD card.
    if(flipflop==HIGH){
      flipflop = LOW;
    }else{
      flipflop = HIGH;
    }
      digitalWrite(LEDPIN, flipflop);   // set the LED
    //delay(10000);
  }  
  // if the file isn't open, pop up an error:
  else {
    #ifdef TESTSERIALOUT
      Serial.println("error opening datalog.txt");
    #endif
  } 
}

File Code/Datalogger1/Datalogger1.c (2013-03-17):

//Wireless in Home Power Monitoring Datalogger
//Copyright Arthur Moore 2012
 

//Uncomment this to enable aditional debugging output
//#define DEBUGOUT 1

#define RADIOOUT 1

//How many measurements we want
#define MAX_MEASUREMENTS 1000


//This set's my Timer0 frequency (Timer1 counts up to 65535)
//Empirical evidence has shown that with current code, the max sampling frequency is 4086 HZ
#define SAMPLING_FREQUENCY 3000
#define PRESCALER 1
#define TARGET_TIMER_COUNT (((F_CPU / PRESCALER) / SAMPLING_FREQUENCY) - 1)

//macros to turn these #defines into strings when needed (the precompiler is weird)
#define STRINGIFY(str) TOSTR(str)
#define TOSTR(str) #str

#include <avr/io.h>
#include <avr/interrupt.h>
#include <util/delay.h>
#include <util/atomic.h>
#include <stdlib.h>
#include <string.h>
#include "adc.h"
#include "measurement.h"
#include "radio/communication.h"
#include "radio/LED.h"
#include "radio/radio.h"

volatile uint16_t cyclesCompleted;

#ifdef RADIOOUT
unsigned int counter = 0;
radioFrame aFrame;
#endif

//This converts all spaces in a string to zeros
void SpaceToZero(char* str,int length){
	int i;
	for(i=0;i<length;i++){
		if (str[i]==' '){
			str[i]='0';
		}
	}
}

void timer_setup(){
	#if TARGET_TIMER_COUNT > 65535
		#error TARGET_TIMER_COUNT is too large
	#endif
	#if PRESCALER == 1
		TCCR1B = _BV(CS10);						//Set our Prescaler to 1
	#elif PRESCALER == 8
		TCCR1B = _BV(CS11);						//Set our Prescaler to 8
	#elif PRESCALER == 64
		TCCR1B = _BV(CS10) | _BV(CS11);			//Set our Prescaler to 64
	#elif PRESCALER == 256
		TCCR1B = _BV(CS12)						//Set our Prescaler to 256
	#elif PRESCALER == 1024
		TCCR1B = _BV(CS10) | _BV(CS12);			//Set our Prescaler to 1024
	#else
		#error Prescaler value is incorrect
	#endif
	
		
	OCR1A = TARGET_TIMER_COUNT;	//Timer counts up to this value
	TCCR1B |= _BV(WGM12);		//Count up to the value in OCR1A
	TIMSK1 = _BV(OCIE1A);		//Enable timer interrupt A

}

struct measurements Voltage;					//This is the struct that holds our voltage measurements
struct measurements Amperage;					//This is the struct that holds our amperage measurements


void setup()
{
	//Disable interupts during setup
	cli();
	//Set up communication
	communication_setup();
	//Set up the ADC
	ADC_setup();
	//Set up the radio
	#ifdef RADIOOUT
	radio_setup();
	//Set up the radio frame to be sent
	aFrame.fcf.dstAddrMode = SIXTEEN;
	aFrame.fcf.srcAddrMode = SIXTEEN;
	aFrame.dstAddr.pan_id = 0x1234;
	aFrame.dstAddr.address = 0x5678;
	aFrame.srcAddr.pan_id = 0x9ABC;
	aFrame.srcAddr.address = 0xDEF0;
	#endif
	
	//Clear the structs in preparation of the first cycle
	NewMeasurement(0,&Voltage);
	NewMeasurement(1,&Amperage);
	//Start timer1
	cyclesCompleted = 0;
	timer_setup();
  
	BlinkLED(1000,1);

	#ifdef DEBUGOUT
	printf("TARGET_TIMER_COUNT: %li\n\r",TARGET_TIMER_COUNT); //Can't stringify this without figuring out how to get the preprocessor to evaluate it
	printf("Sampling "STRINGIFY(MAX_MEASUREMENTS)" Measurements at "STRINGIFY(SAMPLING_FREQUENCY)" HZ\n\r");
	printf("Initalization Completed\n\r");
	#endif
	//Enable interupts (mainly the timer, and ADC interupts)
	sei();
}

//This is what prints the output
//Sample output:		A=00.04&V=003.00&W=0000.12
void sendInfo(){	
	const int outputSize = 28;
	char buffer[8];					//This is the buffer used by dtostrf
	char output[outputSize] = "";		//This string holds the final output
	
	dtostrf(Amperage.average,5,2,buffer);
	SpaceToZero(buffer,8);
	strcat(output,"A=");
	strcat(output,buffer);
	dtostrf(Voltage.average,6,2,buffer);
	SpaceToZero(buffer,8);
	strcat(output,"&V=");
	strcat(output,buffer);
	dtostrf(Voltage.average * Amperage.average,7,2,buffer);
	SpaceToZero(buffer,8);
	strcat(output,"&W=");
	strcat(output,buffer);
	strcat(output,"\n\r");
	
	printf("%s",output);
	#ifdef RADIOOUT
	aFrame.sequenceNumber = counter++;
	aFrame.data = output;
	radio_Frame_write(aFrame);
	#endif
}

#ifdef DEBUGOUT
void debugInfo(){
	char buffer[8];
	//Print out the Reference voltage our ADC is using
	//It should be 3.3V
	dtostrf(Get_Vref(),4,2,buffer);
	printf("Reference Voltage is:  %s\n\r",buffer);
	printf("\n\rBegining Sampling Sequence\n\r");
	
	printf("Sampling Completed\n\r");
	dtostrf(Voltage.average,6,2,buffer);
	printf("%s V Average;",buffer);
	dtostrf(Voltage.RMS,6,2,buffer);
	printf("%s V RMS;",buffer);
	printf("%i samples for V; ",Voltage.numSamples);
	printf("%li totalAverage for V; ",Voltage.totalAverage);
	printf("%li totalRMS for V; ",Voltage.totalRMS);
	printf("\n\r");
	dtostrf(Amperage.average,5,2,buffer);
	printf("%s A Average;",buffer);
	dtostrf(Amperage.RMS,5,2,buffer);
	printf("%s A RMS;",buffer);
	printf("%i samples for A; ",Amperage.numSamples);
	printf("%li totalAverage for A; ",Amperage.totalAverage);
	printf("%li totalRMS for A; ",Amperage.totalRMS);
	printf("\n\r");
}
#endif

//A quick mutex so I can track whether I'm going to fast or not.
volatile int measurement_lock = 0;

//This is triggered by my timer
ISR(TIMER1_COMPA_vect){
//ISR(TIMER1_COMPA_vect,ISR_NOBLOCK){
	//printf(".");
	measurement_lock++;
	if(cyclesCompleted < MAX_MEASUREMENTS){
		//If we're sampling too fast, stop and tell the user.
		//Warning:  Sometimes this still doesn't catch it, and the takeMeasurement functions themselves do and block/hang forever
		if(measurement_lock > 1){
			ATOMIC_BLOCK(ATOMIC_RESTORESTATE){
				printf("Warning:  Sampling frequency <"STRINGIFY(SAMPLING_FREQUENCY)"> too fast!!!\n\r");
				BlinkLED(100,20);
				_delay_ms(1000);
			}
		}else{
			takeMeasurement(&Voltage);
			takeAMeasurement(&Amperage);
			cyclesCompleted++;
		}
	} else {
		if(measurement_lock == 1){
			//Calculate the results
			Calculate_V_Result(&Voltage);
			Calculate_A_Result(&Amperage);
			
			//Send the results
			#ifdef DEBUGOUT
			debugInfo();
			#endif
			sendInfo();
			
			//Clear the structs in preparation for a new cycle
			NewMeasurement(0,&Voltage);
			NewMeasurement(1,&Amperage);
			
			//Toggle the LED to let us know that we're done with a cycle
			BlinkLED(100,1);
			
			//Reset the number of cycles completed
			cyclesCompleted = 0;
		}
	}
	measurement_lock--;
}

//This is in case something went wrong
ISR(BADISR_vect){
	cli();
	for(;;){
		ATOMIC_BLOCK(ATOMIC_RESTORESTATE){
			printf("Warning:  Uncaught Interupt Detected!!!");
			BlinkLED(100,20);
			_delay_ms(1000);
		}
	}
}

int main(){
	setup();
	for(;;){}
	return 0;
}

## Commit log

2012-02-25 Moved all the files into trunk where they belong.
    Here is how you get your local copy to look the same as before:
    1. Right click the folder that had everything in it.
    2. Select the TortoiseSVN drop down menu
    3. Click the "Relocate" option.
    4. Put "https://cd-net.net/CPE496/trunk" in the dialog box.
    5. Click "OK"
    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
    [MicroSDBreakout-V1.brd, MicroSDBreakout-V1.sch, Parts List (Keep Me Updated).xlsx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]
2012-02-26 Fixed a few things in the Main Board.
    I updated the main board to use the new Radio part.
    I also changed the ground plane distance to 20 mil.
    --Arthur
    [gr10-1.brd, gr10-1.sch]
2012-02-26 The Radio Board is now ready to be used with a 10 pin header.
    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
    [Radio Board.brd, Radio Board.sch]
2012-02-26 The MicroSD Breakout board is now ready to be used with a 10 pin header.
    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
    [MicroSDBreakout-V1.brd]
2012-02-26 MicroSD Breakout Board now has a pull up resistor on CS
    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
    [MicroSDBreakout-V1.brd, MicroSDBreakout-V1.sch]
2012-02-26 Radio Board now has pull up resistors on Radio Reset, and Radio CS.
    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
    [Radio Board.brd, Radio Board.sch]
2012-03-02 Removed Files for Printing
    Files for Printing are something I'm using locally.
    There is no need for them to be in the repository.
    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
2012-03-02 Updated Boards
    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
    [MicroSDBreakout-V1.brd, Radio Board.brd, gr10-1.brd]
2012-03-02 Added a main board that uses separate boards for everything.
    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
    [Main Board.brd, Main Board.sch]
2012-03-05 More updates to the Main Board with Headers.
    The transformer will now be under the board, so now we can place things inside that footprint on the top.
    This saves us something around a square inch or two of board space.
    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
    [Main Board.brd, Main Board.sch]
2012-03-06 Latest Update to all the boards.
    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
    [Main Board.brd]
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2012-03-20 Added a simple Arduino script to test whether the prototype board is working or not.
    Blinks the LED
    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
2012-03-20 Added code for use with WinAVR and avrdude.
    This is one way of programing the prototype board.
    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
2012-03-20 Updated "Main Board with Headers" so the ground plane is safely away from AC power.
    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
    [Main Board.brd]
2012-03-20 Added a picture that maps from Arduino pins to our ATMega pins.
    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
2012-03-22 Updated my Datalogger code
    Put the Power Measurement stuff in a separate file that we currently aren't using.
    Cut down on the number of Arduino Functions we're using.
    Using these Arduino Functions:
    3 x pinMode(...) to set the output pins.
    2 x Delay(...) for my LED Blink function.
    Serial.* for debugging (Currently disabled by a #define)
    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
2012-03-22 Datalogger now can use the ADC interrupt.
    I had forgotten about the 'volatile' keyword
    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
2012-03-23 Headers board now has the SD Card holder integrated into it.
    This saves us board space, and brings us one step closer to a nice integrated board.
    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
    [Main Board.brd, Main Board.sch]
2012-03-23 Panelized the Radio board and Main Board.
    Basically main Board with Headers is being turned into the new Main Board.
    I've already attached the SD Card holder.
    Next step is to integrate these two boards, instead of just panelizing them.
    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
    [Main Board.brd, Main Board.sch]
2012-03-23 Cleaned up the Board some in preparation for integration.
    TODO:
    Fix the Radio Part in the library to reflect the ground plane on the device.
    Consider putting either the balun and antenna or the crystal oscilator on the bottom of the board.
    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
    [Main Board.brd]
2012-03-24 Code Update
    I've included everything I use to program my board except the Arduino compiler.
    It's looking like averaging is working instead of RMS for some unknown reason right now, but I need to get a variable voltage source/current sync and check this.
    In other news the transformer seems to be putting out more voltage than it should. It's supposed to be a 23:1 Ratio, but I was measuring 6.4V on the secondaries and my Kill-A-Watt was saying 123V on 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
    Get a variable voltage source/current sync and test the linearity of my measurements.
    If they're linear, then I can account for any weird offsets, ratios.
    --Arthur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
2012-03-25 Main Board with Headers is now almost ready.
    I'm adding the FTDI Module right now.
    1. Double check regulator Datasheet. I think we're missing a capacitor.
    2. Update Radio Module Schematics to incorporate ground plane.
    3. Check if the hall effect sensor can work linearly at 3.3V
    4. Finish Adding FTDI chip and USB connector.
    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
    [Main Board.brd, Main Board.sch, MicroSDBreakout-V1.brd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]
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2012-03-25 Added data sheets for the FTDI chip and the USB connector.
    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
2012-03-25 Added USB to Serial Capability to the board.
    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
    [Main Board.brd, Main Board.sch]
2012-03-25 Library update.
    Radio Board package now has a ground plane.
    The tPlace layer now correctly outlines the chip
    Mark Pin 1 on the tPlace layer.
    Adjust the symbol so that all the pins are grid aligned.
    Make sure that the pin spacing is correct.
    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
2012-03-27 Updated Parts List
    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
    [Parts List (Keep Me Updated).xlsx]
2012-03-28 Added more data sheets.
    Added:
    A data sheet that has the recommended layout for QFN 32 pin size/spacing.
    A data sheet for the Female Edison connector we're using.
    A data sheet for the Euro connector we're using.
    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
2012-03-28 Updated Parts List --Arthur
    [Parts List (Keep Me Updated).xlsx]
2012-03-28 Updated the Board we're having made.
    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
    [Main Board.brd, Main Board.sch]
2012-03-28 Updated Library.
    This is the Library used for the Rev A board.
    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
2012-03-28 Modified Price List
    This is the final price list for everything we need to make 3 boards.
    It does not include the cost of 10AWG wire. (DigiKey wants us to buy to much)
    Also included is a rubric for delivery time vs number of boards.
    This will let us choose the best option for PCB manufacturing.
    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
    [Parts List (Keep Me Updated).xlsx]
2012-04-24 Updated Parts List in Trunk to represent what we really ordered for Rev A.
    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
    [Parts List (Keep Me Updated).xlsx]
2012-04-27 Broken my main Datalogger1 file into some nice sub files.
    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
    [Datalogger1.pde, adc.c]
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2012-04-27 Revamped Datalogger1
    It now prints to the serial port.
    The SD card is currently non-functional.
    Datalogger1 no longer relies on Arduino libraries.
    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
    [Datalogger1.c]
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2012-04-29 Datalogger now correctly samples at the frequency I define.
    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
    [Datalogger1.c]
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2012-04-29 measurement.h in Datalogger no longer references a time variable.
    It was holdove code.
    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
    [Datalogger1.c]
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2012-05-03 Added all of our testing to the repository.
    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
    [DataPoints.xlsx]
2012-10-09 Updated Radio Debugging.
    Now if the radio does not initialize,
    control is returned to main instead of locking forever.
    Main then spits out a warning to the serial port.
    Recursion: The LED no longer works correctly.
    [Datalogger1.c]
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2012-10-09 Use stdlib to replace some of my (bad) functions.
    Unfortunately printf in avr-gcc does not work with floating point numbers.
    I hacked a way around it, and was working on several other attempts for a long term fix.
    It turns out that stdlib can convert everything into nice strings for me.
    [Datalogger1.c]
2012-10-09 Replace functions in debug mode as well.
    I was using my hacked together functions in debug mode.
    Now using stdlib
    [Datalogger1.c]
2012-10-09 Replaced printf with a simple c string print function.
    While printf is nice, it can't handle serial and radio at the same time.
    [Datalogger1.c]
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2012-10-15 The ADC can now execute a function before returning the new value.
    This is done by passing the function and arguments to a special adc function.
    This adds pointer complexity, but avoids the need for and ADC interrupt.
    Measurements now ueses this.
    [adc.c]
2012-10-15 Moved all my communication stuff to a separate file.
    WARNING: I can't get rid of the radio_transmit() function until I fix the reciever.
    Right now the receiver auto adds newlines to every received message.
    [Datalogger1.c]
2012-10-15 Make Timer1 Interrupt blocking.
    The only reason it was non-blocking was the ADC.
    Once that was fixed it was just a liability.
    [Datalogger1.c]
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2012-10-15 Fix an off by one error in the calculations.
    The number of samples was one too high.
    Since it was one out of 1500 it isn't really noticeable.
2012-10-17 Moved the LED stuff to a different file.
    Also fixed a bug in the LED code that was preventing it from working.
    [Datalogger1.c]
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2013-03-17 Fixed a formatting issue with the output.
    dtostrf gives spaces instead of 0s.
    I re-added a function to fix that problem.
    [Datalogger1.c]
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

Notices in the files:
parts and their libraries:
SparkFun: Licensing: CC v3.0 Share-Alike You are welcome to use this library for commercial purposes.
